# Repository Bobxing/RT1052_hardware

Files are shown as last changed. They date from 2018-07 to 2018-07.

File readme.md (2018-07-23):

# RT1052_hardware #

RT1052_hardware包含了野火RT1052系列开发板硬件相关的说明，包含如下内容：
* 原理图
* 机械尺寸图
* RT1052引脚分配表
* 核心板连接器的封装
* 板载元器件的封装

开发者可直接使用以上提供的器件封装，或参考原理图对自己的应用进行定制。

开发板配套的资料如下：
* [野火RT1052开发板配套程序](https://github.com/WildFire-Git/RT1052_code)

* [野火i.MX RT库开发实战指南](https://github.com/WildFire-Git/RT1052_doc)

开发者可直接使用我们的程序进行学习或对应用进行定制。

## 许可证 ##
MIT

## 联系我们 ##
* 电子邮箱:embedfire@embedfire.com
* 野火官网:http://www.embedfire.com
* 野火论坛:http://www.firebbs.cn
* 淘宝店铺:http://fire-stm32.taobao.com

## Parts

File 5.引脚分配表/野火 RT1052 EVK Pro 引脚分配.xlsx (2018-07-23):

 |  |  |  | 开发板分配的第一功能 | 开发板分配的第二功能
核心板引脚编号 | 底板排针引脚编号 | 核心板网络标号 | 芯片引脚定义 | ALT0（复用功能0） | ALT1（复用功能1） | ALT2（复用功能2） | ALT3（复用功能3） | ALT4（复用功能4） | ALT5（复用功能5） | ALT6（复用功能6） | ALT7（复用功能7） | ADC #1 | ADC #2 | ACMP #1 | ACMP #2 | ACMP #3 | ACMP #4
CN2-43 | B-43 | USB_OTG2_ID | GPIO_AD_B0_00 | FLEXPWM2_PWMA03 | XBAR1_INOUT14 | REF_CLK_32K | USB_OTG2_ID | LPI2C1_SCLS | GPIO1_IO00 | USDHC1_RESET_B | LPSPI3_SCK |  |  | ACMP1_IN4
CN2-41 | B-41 | USB_OTG1_ID | GPIO_AD_B0_01 | FLEXPWM2_PWMB03 | XBAR1_INOUT15 | REF_CLK_24M | USB_OTG1_ID | LPI2C1_SDAS | GPIO1_IO01 | EWM_OUT_B | LPSPI3_SDO |  |  |  | ACMP2_IN4
CN2-14 | B-14 | CTP_RST | GPIO_AD_B0_02 | FLEXCAN2_TX | XBAR1_INOUT16 | LPUART6_TX | USB_OTG1_PWR | FLEXPWM1_PWMX00 | GPIO1_IO02 | LPI2C1_HREQ | LPSPI3_SDI |  |  |  |  | ACMP3_IN4
CN2-16 | B-16 | USB OTG OC | GPIO_AD_B0_03 | FLEXCAN2_RX | XBAR1_INOUT17 | LPUART6_RX | USB_OTG1_OC | FLEXPWM1_PWMX01 | GPIO1_IO03 | REF_CLK_24M | LPSPI3_PCS0 |  |  |  |  |  | ACMP4_IN4
CN2-18 | B-18 | LCD_PWR_EN | GPIO_AD_B0_04 | SRC_BOOT_MODE00 | MQS_RIGHT | ENET_TX_DATA03 | SAI2_TX_SYNC | CSI_DATA09 | GPIO1_IO04 | PIT_TRIGGER00 | LPSPI3_PCS1
CN2-20 | B-20 | SD_PWR_EN | GPIO_AD_B0_05 | SRC_BOOT_MODE01 | MQS_LEFT | ENET_TX_DATA02 | SAI2_TX_BCLK | CSI_DATA08 | GPIO1_IO05 | XBAR1_INOUT17 | LPSPI3_PCS2
CN2-3 | B-3 | JTAG_TMS | GPIO_AD_B0_06 | JTAG_TMS | GPT2_COMPARE1 | ENET_RX_CLK | SAI2_RX_BCLK | CSI_DATA07 | GPIO1_IO06 | XBAR1_INOUT18 | LPSPI3_PCS3
CN2-2 | B-2 | JTAG_TCK | GPIO_AD_B0_07 | JTAG_TCK | GPT2_COMPARE2 | ENET_TX_ER | SAI2_RX_SYNC | CSI_DATA06 | GPIO1_IO07 | XBAR1_INOUT19 | ENET_1588_EVENT3_OUT
 |  |  | GPIO_AD_B0_08 | JTAG_MOD | GPT2_COMPARE3 | ENET_RX_DATA03 | SAI2_RX_DATA | CSI_DATA05 | GPIO1_IO08 | XBAR1_IN20 | ENET_1588_EVENT3_IN
CN2-1 | B-1 | JTAG_TDI | GPIO_AD_B0_09 | JTAG_TDI | FLEXPWM2_PWMA03 | ENET_RX_DATA02 | SAI2_TX_DATA | CSI_DATA04 | GPIO1_IO09 | XBAR1_IN21 | GPT2_CLK
CN2-4 | B-4 | JTAG_TDO | GPIO_AD_B0_10 | JTAG_TDO | FLEXPWM1_PWMA03 | ENET_CRS | SAI2_MCLK | CSI_DATA03 | GPIO1_IO10 | XBAR1_IN22 | ENET_1588_EVENT0_OUT
CN2-5 | B-5 | CTP_IRQ | GPIO_AD_B0_11 | JTAG_TRSTB | FLEXPWM1_PWMB03 | ENET_COL | WDOG1_WDOG_B | CSI_DATA02 | GPIO1_IO11 | XBAR1_IN23 | ENET_1588_EVENT0_IN
CN2-9 | B-9 | UART1_TX | GPIO_AD_B0_12 | LPI2C4_SCL | CCM_PMIC_READY | LPUART1_TX | WDOG2_WDOG_B | FLEXPWM1_PWMX02 | GPIO1_IO12 | ENET_1588_EVENT1_OUT |  | ADC1_IN1
CN2-11 | B-11 | UART1_RX | GPIO_AD_B0_13 | LPI2C4_SDA | GPT1_CLK | LPUART1_RX | EWM_OUT_B | FLEXPWM1_PWMX03 | GPIO1_IO13 | ENET_1588_EVENT1_IN | REF_CLK_24M | ADC1_IN2 |  | ACMP1_IN2
CN2-17 | B-17 | CAN2_TX | GPIO_AD_B0_14 | USB_OTG2_OC | XBAR1_IN24 | LPUART1_CTS_B | ENET_1588_EVENT0_OUT | CSI_VSYNC | GPIO1_IO14 | FLEXCAN2_TX |  | ADC1_IN3 |  |  | ACMP2_IN2
CN2-19 | B-19 | CAN2_RX | GPIO_AD_B0_15 | USB_OTG2_PWR | XBAR1_IN25 | LPUART1_RTS_B | ENET_1588_EVENT0_IN | CSI_HSYNC | GPIO1_IO15 | FLEXCAN2_RX | WDOG1_WDOG_RST_B_DEB | ADC1_IN4 |  |  |  | ACMP3_IN2
CN2-21 | B-21 | I2C1_SCL | GPIO_AD_B1_00 | USB_OTG2_ID | QTIMER3_TIMER0 | LPUART2_CTS_B | LPI2C1_SCL | WDOG1_B | GPIO1_IO16 | USDHC1_WP | KPP_ROW07 | ADC1_IN5 | ADC2_IN5 |  |  |  | ACMP4_IN2
CN2-23 | B-23 | I2C1_SDA | GPIO_AD_B1_01 | USB_OTG1_PWR | QTIMER3_TIMER1 | LPUART2_RTS_B | LPI2C1_SDA | CCM_PMIC_READY | GPIO1_IO17 | USDHC1_VSELECT | KPP_COL07 | ADC1_IN6 | ADC2_IN6 | ACMP1_IN0 | ACMP2_IN0 | ACMP3_IN0 | ACMP4_IN0
CN2-10 | B-10 | SPDIF_OUT | GPIO_AD_B1_02 | USB_OTG1_ID | QTIMER3_TIMER2 | LPUART2_TX | SPDIF_OUT | ENET_1588_EVENT2_OUT | GPIO1_IO18 | USDHC1_CD_B | KPP_ROW06 | ADC1_IN7 | ADC2_IN7 | ACMP1_IN3
CN2-8 | B-23 | SPDIF_IN | GPIO_AD_B1_03 | USB_OTG1_OC | QTIMER3_TIMER3 | LPUART2_RX | SPDIF_IN | ENET_1588_EVENT2_IN | GPIO1_IO19 | USDHC2_CD_B | KPP_COL06 | ADC1_IN8 | ADC2_IN8 |  | ACMP2_IN3
CN1-16 | A-16 | GPIO_AD_B1_04 | GPIO_AD_B1_04 | FLEXSPIB_DATA03 | ENET_MDC | LPUART3_CTS_B | SPDIF_SR_CLK | CSI_PIXCLK | GPIO1_IO20 | USDHC2_DATA0 | KPP_ROW05 | ADC1_IN9 | ADC2_IN9 |  |  | ACMP3_IN3
CN2-24 | B-24 | GPIO_AD_B1_05 | GPIO_AD_B1_05 | FLEXSPIB_DATA02 | ENET_MDIO | LPUART3_RTS_B | SPDIF_OUT | CSI_MCLK | GPIO1_IO21 | USDHC2_DATA1 | KPP_COL05 | ADC1_IN10 | ADC2_IN10 |  |  |  | ACMP4_IN3
CN2-26 | B-26 | GPIO_AD_B1_06 | GPIO_AD_B1_06 | FLEXSPIB_DATA01 | LPI2C3_SDA | LPUART3_TX | SPDIF_LOCK | CSI_VSYNC | GPIO1_IO22 | USDHC2_DATA2 | KPP_ROW04 | ADC1_IN11 | ADC2_IN11 | ACMP1_IN1 | ACMP2_IN1 | ACMP3_IN1 | ACMP4_IN1
CN2-28 | B-28 | GPIO_AD_B1_07 | GPIO_AD_B1_07 | FLEXSPIB_DATA00 | LPI2C3_SCL | LPUART3_RX | SPDIF_EXT_CLK | CSI_HSYNC | GPIO1_IO23 | USDHC2_DATA3 | KPP_COL04 | ADC1_IN12 | ADC2_IN12 | ACMP1_IN5
CN2-30 | B-30 | GPIO_AD_B1_08 | GPIO_AD_B1_08 | FLEXSPIA_SS1_B | FLEXPWM4_PWMA00 | FLEXCAN1_TX | CCM_PMIC_READY | CSI_DATA09 | GPIO1_IO24 | USDHC2_CMD | KPP_ROW03 | ADC1_IN13 | ADC2_IN13 |  | ACMP2_IN5
CN2-35 | B-35 | SAI1_MCLK | GPIO_AD_B1_09 | FLEXSPIA_DQS | FLEXPWM4_PWMA01 | FLEXCAN1_RX | SAI1_MCLK | CSI_DATA08 | GPIO1_IO25 | USDHC2_CLK | KPP_COL03 | ADC1_IN14 | ADC2_IN14 |  |  | ACMP3_IN5
CN2-31 | B-31 | SAI1_RX_SYNC | GPIO_AD_B1_10 | FLEXSPIA_DATA03 | WDOG1_B | LPUART8_TX | SAI1_RX_SYNC | CSI_DATA07 | GPIO1_IO26 | USDHC2_WP | KPP_ROW02 | ADC1_IN15 | ADC2_IN15 |  |  |  | ACMP4_IN5
CN2-29 | B-29 | SAI1_RX_BCLK | GPIO_AD_B1_11 | FLEXSPIA_DATA02 | EWM_OUT_B | LPUART8_RX | SAI1_RX_BCLK | CSI_DATA06 | GPIO1_IO27 | USDHC2_RESET_B | KPP_COL02 | ADC1_IN0 | ADC2_IN0 | ACMP1_IN6
CN2-33 | B-33 | SAI1_RXD | GPIO_AD_B1_12 | FLEXSPIA_DATA01 | ACMP_OUT00 | LPSPI3_PCS0 | SAI1_RX_DATA00 | CSI_DATA05 | GPIO1_IO28 | USDHC2_DATA4 | KPP_ROW01 |  | ADC2_IN1 | ACMP1_OUT | ACMP2_IN6
CN2-36 | B-36 | SAI1_TXD | GPIO_AD_B1_13 | FLEXSPIA_DATA00 | ACMP_OUT01 | LPSPI3_SDI | SAI1_TX_DATA00 | CSI_DATA04 | GPIO1_IO29 | USDHC2_DATA5 | KPP_COL01 |  | ADC2_IN2 |  | ACMP2_OUT | ACMP3_IN6
CN2-34 | B-34 | SAI1_TX_BCLK | GPIO_AD_B1_14 | FLEXSPIA_SCLK | ACMP_OUT02 | LPSPI3_SDO | SAI1_TX_BCLK | CSI_DATA03 | GPIO1_IO30 | USDHC2_DATA6 | KPP_ROW00 |  | ADC2_IN3 |  |  | ACMP3_OUT | ACMP4_IN6
CN2-32 | B-32 | SAI1_TX_SYNC | GPIO_AD_B1_15 | FLEXSPIA_SS0_B | ACMP_OUT03 | LPSPI3_SCK | SAI1_TX_SYNC | CSI_DATA02 | GPIO1_IO31 | USDHC2_DATA7 | KPP_COL00 |  | ADC2_IN4 |  |  |  | ACMP4_OUT
CN1-37 | A-37 | LCDIF_CLK | GPIO_B0_00 | LCD_CLK | QTIMER1_TIMER0 | MQS_RIGHT | LPSPI4_PCS0 | FLEXIO2_FLEXIO00 | GPIO2_IO00 | SEMC_CSX01
CN1-38 | A-38 | LCDIF_ENA | GPIO_B0_01 | LCD_ENABLE | QTIMER1_TIMER1 | MQS_LEFT | LPSPI4_SDI | FLEXIO2_FLEXIO01 | GPIO2_IO01 | SEMC_CSX02
CN1-36 | A-36 | LCDIF_HSYNC | GPIO_B0_02 | LCD_HSYNC | QTIMER1_TIMER2 | FLEXCAN1_TX | LPSPI4_SDO | FLEXIO2_FLEXIO02 | GPIO2_IO02 | SEMC_CSX03
CN1-35 | A-35 | LCDIF_VSYNC | GPIO_B0_03 | LCD_VSYNC | QTIMER2_TIMER0 | FLEXCAN1_RX | LPSPI4_SCK | FLEXIO2_FLEXIO03 | GPIO2_IO03 | WDOG2_RESET_B_DEB
CN1-19 | A-19 | LCDIF_D0 (B3) | GPIO_B0_04 | LCD_DATA00 (B3) | QTIMER2_TIMER1 | LPI2C2_SCL |  | FLEXIO2_FLEXIO04 | GPIO2_IO04 | SRC_BOOT_CFG00
CN1-20 | A-20 | LCDIF_D1 (B4) | GPIO_B0_05 | LCD_DATA01 (B4) | QTIMER2_TIMER2 | LPI2C2_SDA |  | FLEXIO2_FLEXIO05 | GPIO2_IO05 | SRC_BOOT_CFG01
CN1-21 | A-21 | LCDIF_D2 (B5) | GPIO_B0_06 | LCD_DATA02 (B5) | QTIMER3_TIMER0 | FLEXPWM2_PWMA00 |  | FLEXIO2_FLEXIO06 | GPIO2_IO06 | SRC_BOOT_CFG02
CN1-22 | A-22 | LCDIF_D3 (B6) | GPIO_B0_07 | LCD_DATA03 (B6) | QTIMER3_TIMER1 | FLEXPWM2_PWMB00 |  | FLEXIO2_FLEXIO07 | GPIO2_IO07 | SRC_BOOT_CFG03
CN1-23 | A-23 | LCDIF_D4 (B7) | GPIO_B0_08 | LCD_DATA04 (B7) | QTIMER3_TIMER2 | FLEXPWM2_PWMA01 | LPUART3_TX | FLEXIO2_FLEXIO08 | GPIO2_IO08 | SRC_BOOT_CFG04
CN1-24 | A-24 | LCDIF_D5 (G2) | GPIO_B0_09 | LCD_DATA05 (G2) | QTIMER4_TIMER0 | FLEXPWM2_PWMB01 | LPUART3_RX | FLEXIO2_FLEXIO09 | GPIO2_IO09 | SRC_BOOT_CFG05
CN1-25 | A-25 | LCDIF_D6 (G3) | GPIO_B0_10 | LCD_DATA06 (G3) | QTIMER4_TIMER1 | FLEXPWM2_PWMA02 | SAI1_TX_DATA03 | FLEXIO2_FLEXIO10 | GPIO2_IO10 | SRC_BOOT_CFG06
CN1-26 | A-26 | LCDIF_D7 (G4) | GPIO_B0_11 | LCD_DATA07 (G4) | QTIMER4_TIMER2 | FLEXPWM2_PWMB02 | SAI1_TX_DATA02 | FLEXIO2_FLEXIO11 | GPIO2_IO11 | SRC_BOOT_CFG07
CN1-27 | A-27 | LCDIF_D8 (G5) | GPIO_B0_12 | LCD_DATA08 (G5) | XBAR1_INOUT10 |  | SAI1_TX_DATA01 | FLEXIO2_FLEXIO12 | GPIO2_IO12 | SRC_BOOT_CFG08
CN1-28 | A-28 | LCDIF_D9 (G6) | GPIO_B0_13 | LCD_DATA09 (G6) | XBAR1_INOUT11 |  | SAI1_MCLK | FLEXIO2_FLEXIO13 | GPIO2_IO13 | SRC_BOOT_CFG09
CN1-29 | A-29 | LCDIF_D10 (G7) | GPIO_B0_14 | LCD_DATA10 (G7) | XBAR1_INOUT12 | ARM_CM7_TXEV | SAI1_RX_SYNC | FLEXIO2_FLEXIO14 | GPIO2_IO14 | SRC_BOOT_CFG10
CN1-30 | A-30 | LCDIF_D11 (R3) | GPIO_B0_15 | LCD_DATA11 (R3) | XBAR1_INOUT13 | ARM_CM7_RXEV | SAI1_RX_BCLK | FLEXIO2_FLEXIO15 | GPIO2_IO15 | SRC_BOOT_CFG11
CN1-31 | A-31 | LCDIF_D12 (R4) | GPIO_B1_00 | LCD_DATA12 (R4) | XBAR1_INOUT14 | LPUART4_TX | SAI1_RX_DATA00 | FLEXIO2_FLEXIO16 | GPIO2_IO16 | FLEXPWM1_PWMA03
CN1-32 | A-32 | LCDIF_D13 (R5) | GPIO_B1_01 | LCD_DATA13 (R5) | XBAR1_INOUT15 | LPUART4_RX | SAI1_TX_DATA00 | FLEXIO2_FLEXIO17 | GPIO2_IO17 | FLEXPWM1_PWMB03
CN1-33 | A-33 | LCDIF_D14 (R6) | GPIO_B1_02 | LCD_DATA14 (R6) | XBAR1_INOUT16 | LPSPI4_PCS2 | SAI1_TX_BCLK | FLEXIO2_FLEXIO18 | GPIO2_IO18 | FLEXPWM2_PWMA03
CN1-34 | A-34 | LCDIF_D15 (R7) | GPIO_B1_03 | LCD_DATA15 (R7) | XBAR1_INOUT17 | LPSPI4_PCS1 | SAI1_TX_SYNC | FLEXIO2_FLEXIO19 | GPIO2_IO19 | FLEXPWM2_PWMB03
CN1-10 | A-10 | ENET_RXD0 | GPIO_B1_04 | LCD_DATA16 | LPSPI4_PCS0 | CSI_DATA15 | ENET_RX_DATA00 | FLEXIO2_FLEXIO20 | GPIO2_IO20
CN1-12 | A-12 | ENET_RXD1 | GPIO_B1_05 | LCD_DATA17 | LPSPI4_SDI | CSI_DATA14 | ENET_RX_DATA01 | FLEXIO2_FLEXIO21 | GPIO2_IO21
CN1-15 | A-15 | ENET_CRS_DV | GPIO_B1_06 | LCD_DATA18 | LPSPI4_SDO | CSI_DATA13 | ENET_RX_EN | FLEXIO2_FLEXIO22 | GPIO2_IO22
CN1-11 | A-11 | ENET_TXD0 | GPIO_B1_07 | LCD_DATA19 | LPSPI4_SCK | CSI_DATA12 | ENET_TX_DATA00 | FLEXIO2_FLEXIO23 | GPIO2_IO23
CN1-13 | A-13 | ENET_TXD1 | GPIO_B1_08 | LCD_DATA20 | QTIMER1_TIMER3 | CSI_DATA11 | ENET_TX_DATA01 | FLEXIO2_FLEXIO24 | GPIO2_IO24 | FLEXCAN2_TX
CN1-9 | A-9 | ENET_TXEN | GPIO_B1_09 | LCD_DATA21 | QTIMER2_TIMER3 | CSI_DATA10 | ENET_TX_EN | FLEXIO2_FLEXIO25 | GPIO2_IO25 | FLEXCAN2_RX
CN1-17 | A-17 | ENET_TXCLK | GPIO_B1_10 | LCD_DATA22 | QTIMER3_TIMER3 | CSI_DATA00 | ENET_TX_CLK | FLEXIO2_FLEXIO26 | GPIO2_IO26 | ENET_REF_CLK
CN1-14 | A-14 | ENET_RXER | GPIO_B1_11 | LCD_DATA23 | QTIMER4_TIMER3 | CSI_DATA01 | ENET_RX_ER | FLEXIO2_FLEXIO27 | GPIO2_IO27 | LPSPI4_PCS3
CN2-13 | B-13 | UART5_TX | GPIO_B1_12 |  | LPUART5_TX | CSI_PIXCLK | ENET_1588_EVENT0_IN | FLEXIO2_FLEXIO28 | GPIO2_IO28 | USDHC1_CD_B
CN2-15 | B-15 | UART5_RX | GPIO_B1_13 | WDOG1_B | LPUART5_RX | CSI_VSYNC | ENET_1588_EVENT0_OUT | FLEXIO2_FLEXIO29 | GPIO2_IO29 | USDHC1_WP
CN2-63 | B-63 | SD0_VSELECT | GPIO_B1_14 | ENET_MDC | FLEXPWM4_PWMA02 | CSI_HSYNC | XBAR1_IN02 | FLEXIO2_FLEXIO30 | GPIO2_IO30 | USDHC1_VSELECT
CN1-18 | A-18 | ENET_MDIO | GPIO_B1_15 | ENET_MDIO | FLEXPWM4_PWMA03 | CSI_MCLK | XBAR1_IN03 | FLEXIO2_FLEXIO31 | GPIO2_IO31 | USDHC1_RESET_B
CN2-68 | B-68 | SD_CMD | GPIO_SD_B0_00 | USDHC1_CMD | FLEXPWM1_PWMA00 | LPI2C3_SCL | XBAR1_INOUT04 | LPSPI1_SCK | GPIO3_IO12 | FLEXSPIA_SS1_B
CN2-70 | B-70 | SD_CLK | GPIO_SD_B0_01 | USDHC1_CLK | FLEXPWM1_PWMB00 | LPI2C3_SDA | XBAR1_INOUT05 | LPSPI1_PCS0 | GPIO3_IO13 | FLEXSPIB_SS1_B
CN2-65 | B-65 | SD_D0 | GPIO_SD_B0_02 | USDHC1_DATA0 | FLEXPWM1_PWMA01 | LPUART8_CTS_B | XBAR1_INOUT06 | LPSPI1_SDO | GPIO3_IO14
CN2-67 | B-67 | SD_D1 | GPIO_SD_B0_03 | USDHC1_DATA1 | FLEXPWM1_PWMB01 | LPUART8_RTS_B | XBAR1_INOUT07 | LPSPI1_SDI | GPIO3_IO15
CN2-69 | B-69 | SD_D2 | GPIO_SD_B0_04 | USDHC1_DATA2 | FLEXPWM1_PWMA02 | LPUART8_TX | XBAR1_INOUT08 | FLEXSPIB_SS0_B | GPIO3_IO16 | CCM_CLKO1
CN2-66 | B-66 | SD_D3 | GPIO_SD_B0_05 | USDHC1_DATA3 | FLEXPWM1_PWMB02 | LPUART8_RX | XBAR1_INOUT09 | FLEXSPIB_DQS | GPIO3_IO17 | CCM_CLKO2
CN2-62 | B-62 | FlexSPI_D3_B | GPIO_SD_B1_00 | USDHC2_DATA3 | FLEXSPIB_DATA03 | FLEXPWM1_PWMA03 | SAI1_TX_DATA03 | LPUART4_TX | GPIO3_IO00
CN2-60 | B-60 | FlexSPI_D2_B | GPIO_SD_B1_01 | USDHC2_DATA2 | FLEXSPIB_DATA02 | FLEXPWM1_PWMB03 | SAI1_TX_DATA02 | LPUART4_RX | GPIO3_IO01
CN2-58 | B-58 | FlexSPI_D1_B | GPIO_SD_B1_02 | USDHC2_DATA1 | FLEXSPIB_DATA01 | FLEXPWM2_PWMA03 | SAI1_TX_DATA01 | FLEXCAN1_TX | GPIO3_IO02 | CCM_WAIT
CN2-56 | B-56 | FlexSPI_D0_B | GPIO_SD_B1_03 | USDHC2_DATA0 | FLEXSPIB_DATA00 | FLEXPWM2_PWMB03 | SAI1_MCLK | FLEXCAN1_RX | GPIO3_IO03 | CCM_PMIC_READY
CN2-54 | B-54 | FlexSPI_CLK_B | GPIO_SD_B1_04 | USDHC2_CLK | FLEXSPIB_SCLK | LPI2C1_SCL | SAI1_RX_SYNC | FLEXSPIA_SS1_B | GPIO3_IO04 | CCM_STOP
CN2-52 | B-52 | FlexSPI_DQS | GPIO_SD_B1_05 | USDHC2_CMD | FLEXSPIA_DQS | LPI2C1_SDA | SAI1_RX_BCLK | FLEXSPIB_SS0_B | GPIO3_IO05
CN2-51 | B-51 | FlexSPI_SS0 | GPIO_SD_B1_06 | USDHC2_RESET_B | FLEXSPIA_SS0_B | LPUART7_CTS_B | SAI1_RX_DATA00 | LPSPI2_PCS0 | GPIO3_IO06
CN2-53 | B-53 | FlexSPI_CLK | GPIO_SD_B1_07 | SEMC_CSX01 | FLEXSPIA_SCLK | LPUART7_RTS_B | SAI1_TX_DATA00 | LPSPI2_SCK | GPIO3_IO07 | CCM_REF_EN_B
CN2-55 | B-55 | FlexSPI_D0_A | GPIO_SD_B1_08 | USDHC2_DATA4 | FLEXSPIA_DATA00 | LPUART7_TX | SAI1_TX_BCLK | LPSPI2_SD0 | GPIO3_IO08 | SEMC_CSX02
CN2-57 | B-57 | FlexSPI_D1_A | GPIO_SD_B1_09 | USDHC2_DATA5 | FLEXSPIA_DATA01 | LPUART7_RX | SAI1_TX_SYNC | LPSPI2_SDI | GPIO3_IO09
CN2-59 | B-59 | FlexSPI_D2_A | GPIO_SD_B1_10 | USDHC2_DATA6 | FLEXSPIA_DATA02 | LPUART2_RX | LPI2C2_SDA | LPSPI2_PCS2 | GPIO3_IO10
CN2-61 | B-61 | FlexSPI_D3_A | GPIO_SD_B1_11 | USDHC2_DATA7 | FLEXSPIA_DATA03 | LPUART2_TX | LPI2C2_SCL | LPSPI2_PCS3 | GPIO3_IO11
CN2-25 | B-25 | GPIO_EMC_40 | GPIO_EMC_40 | SEMC_RDY | GPT2_CAPTURE2 | LPSPI1_PCS2 | USB_OTG2_OC | ENET_MDC | GPIO3_IO26 | USDHC2_RESET_B
CN2-27 | B-27 | GPIO_EMC_41 | GPIO_EMC_41 | SEMC_CSX00 | GPT2_CAPTURE1 | LPSPI1_PCS3 | USB_OTG2_PWR | ENET_MDIO | GPIO3_IO27 | USDHC1_VSELECT
CN2-37 | B-37 | CLK1_OUT_N
CN2-39 | B-39 | CLK1_OUT_P
CN2-38 | B-37 | OTG1_DP
CN2-40 | B-39 | OTG1_DN
CN2-42 | B-37 | OTG2_DN
CN2-44 | B-39 | OTG2_DP
CN2-50 | B-50 | ONOFF |  | SRC_RESET_B
CN2-47 | B-47 | POR_B |  | SRC_POR_B
CN2-48 | B-48 | KEY |  |  |  |  |  |  | GPIO5_IO00
CN2-49 | B-49 | PMIC_ON |  | CCM_PMIC_ON_REQ |  |  |  |  | GPIO5_IO01
CN2-45 | B-45 | PMIC_STBY |  | CCM_PMIC_VSTBY_REQ |  |  |  |  | GPIO5_IO01

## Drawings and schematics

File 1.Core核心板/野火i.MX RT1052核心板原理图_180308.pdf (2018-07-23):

D

C

B

A | A

目录

# Page 1 目录

# 野火i.MX RT1052核心板

# Page 2

# Page 3

# Page 4

# Page 5

# Page 6

# Page 8

# Page 7

# 历史版本

# 主电源

## MCU电源

## SDRAM

## MCU_GPIO

## LCD/KEY/BOOT CFG

SD

Page 9 | NAND FLASH/QSPI FLASH/E2PROM
Page 10 Page 11 | USB/JTAG/UART
| ETHERNET
Page 12 | 引出IO

Title

Size | Document Number | Rev
Date: | Sheet | of
目录 | V1.0

野火i.MX RT1052核心板

东莞野火电子技术有限公司
https://fire-stm32.taobao.com

A4

Thursday, March 08, 2018 | 1 | 12

Title

目录 | V1.0

野火i.MX RT1052核心板

东莞野火电子技术有限公司
https://fire-stm32.taobao.com
Thursday, March 08, 2018 | 1 | 12

Title

目录 | V1.0

野火i.MX RT1052核心板

东莞野火电子技术有限公司
https://fire-stm32.taobao.com
Thursday, March 08, 2018 | 1 | 12

D

C

B

A | A

# 历史版本

# 版本号

V0.1 | 2017-12-04
日期 | 设计 | 描述
| cancore | 初始版本
V0.2 | 2017-12-26 | cancore | 1.增加I2C上拉电阻 | 2.删除调试口电源供电，避免上电时序出错
V0.3 | 2018-01-13 | cancore | 1.Q2封装更正 2.SEMC_RDY增加上拉 3.C72不焊
V1.0 | 2018-02-6 | cancore | 1.删除WDOG相关电路 2.RTC供电串联100Ω电阻 3.USB供电增加保护电路

Title

历史版本 | V1.0

野火i.MX RT1052核心板

东莞野火电子技术有限公司
https://fire-stm32.taobao.com
Thursday, March 08, 2018 | 2 | 12

Title

历史版本 | V1.0

野火i.MX RT1052核心板

东莞野火电子技术有限公司
https://fire-stm32.taobao.com
Thursday, March 08, 2018 | 2 | 12

Title

历史版本 | V1.0

野火i.MX RT1052核心板

东莞野火电子技术有限公司
https://fire-stm32.taobao.com
Thursday, March 08, 2018 | 2 | 12

D

# R36/R39 = 4.5

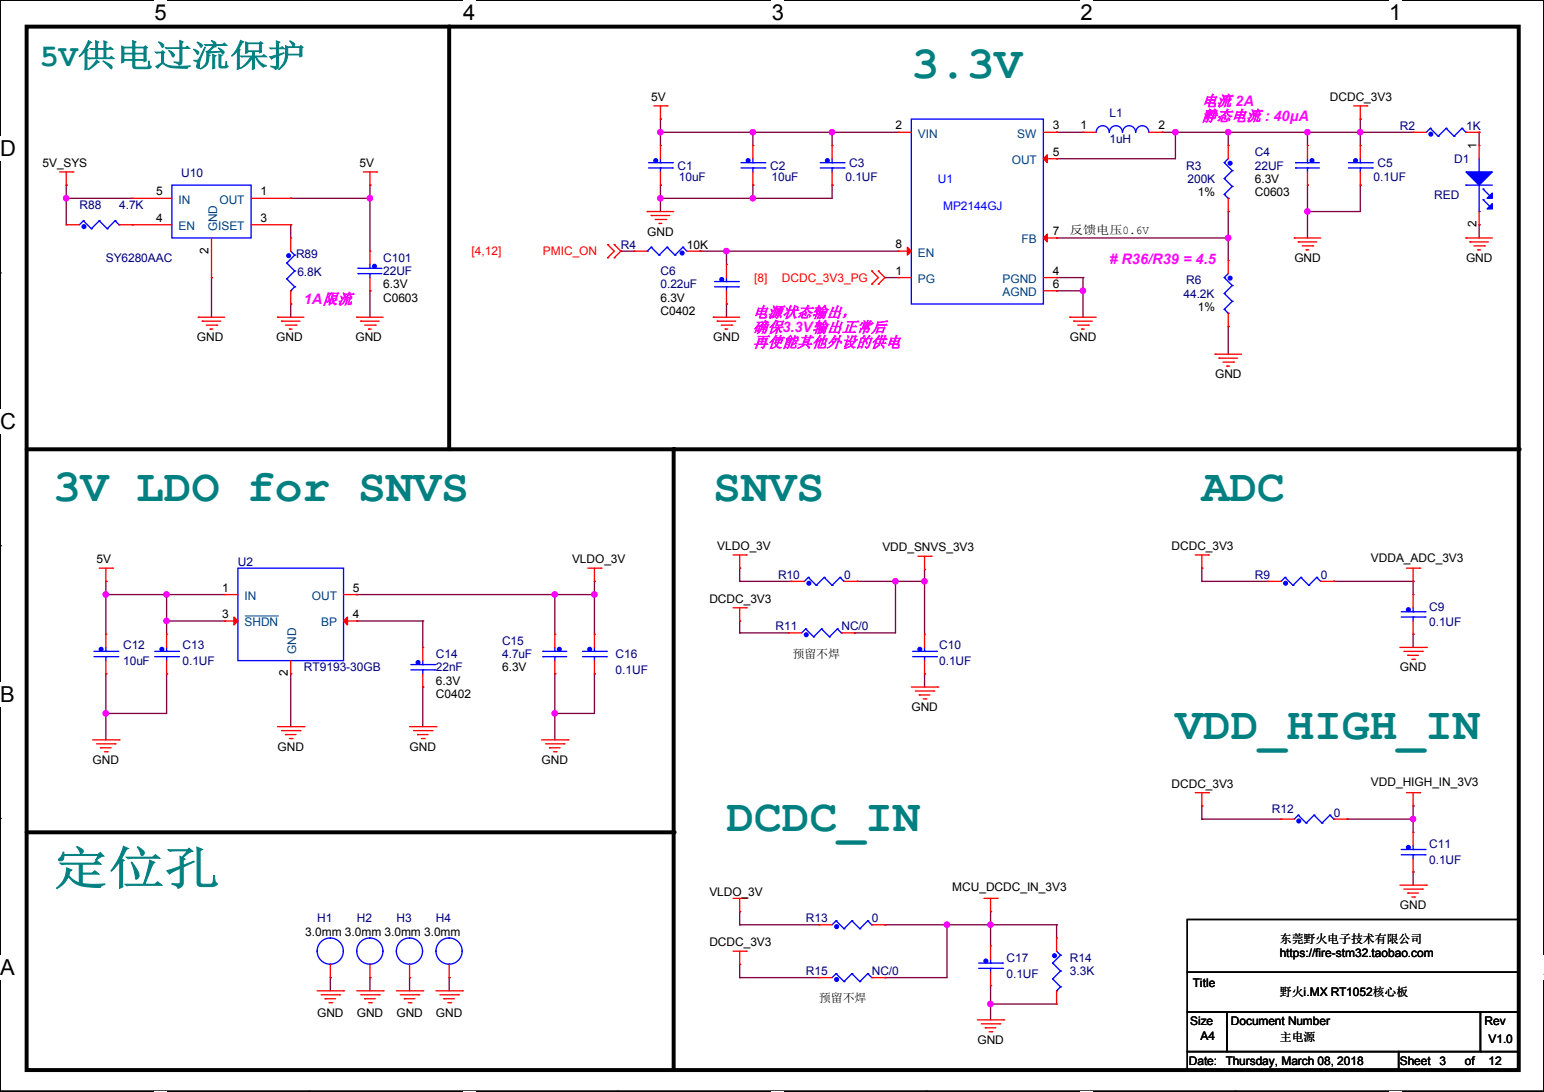
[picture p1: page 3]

东莞野火电子技术有限公司
https://fire-stm32.taobao.com

D

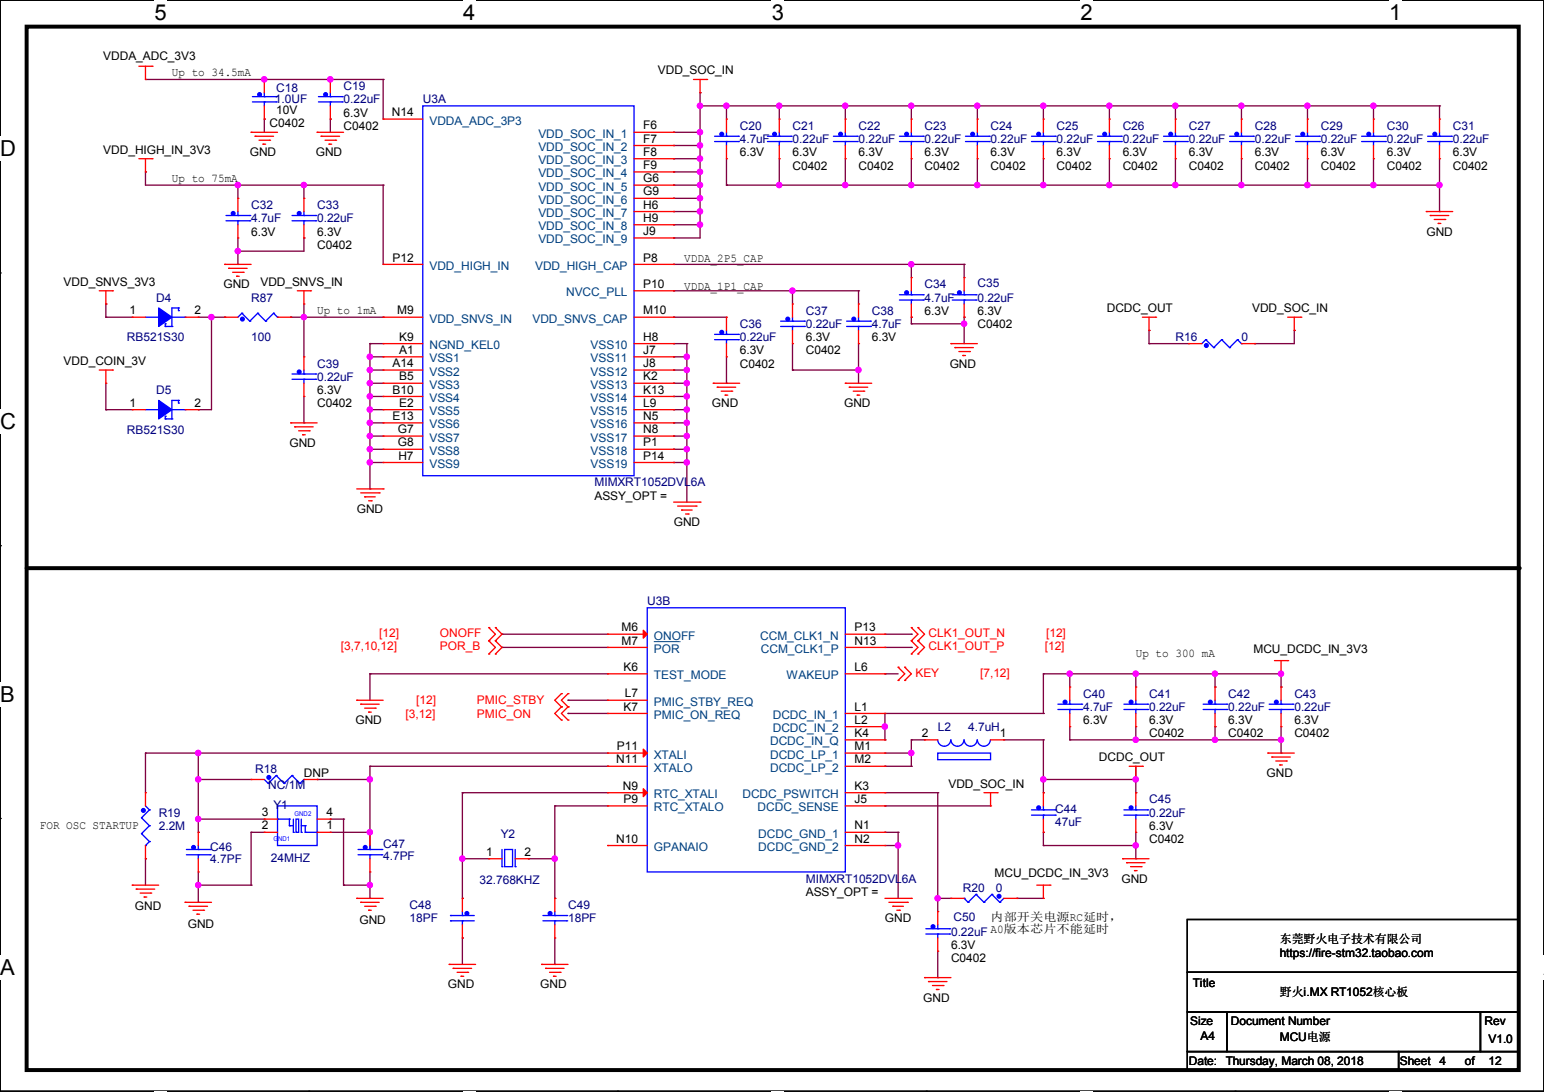
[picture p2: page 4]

东莞野火电子技术有限公司
https://fire-stm32.taobao.com

D

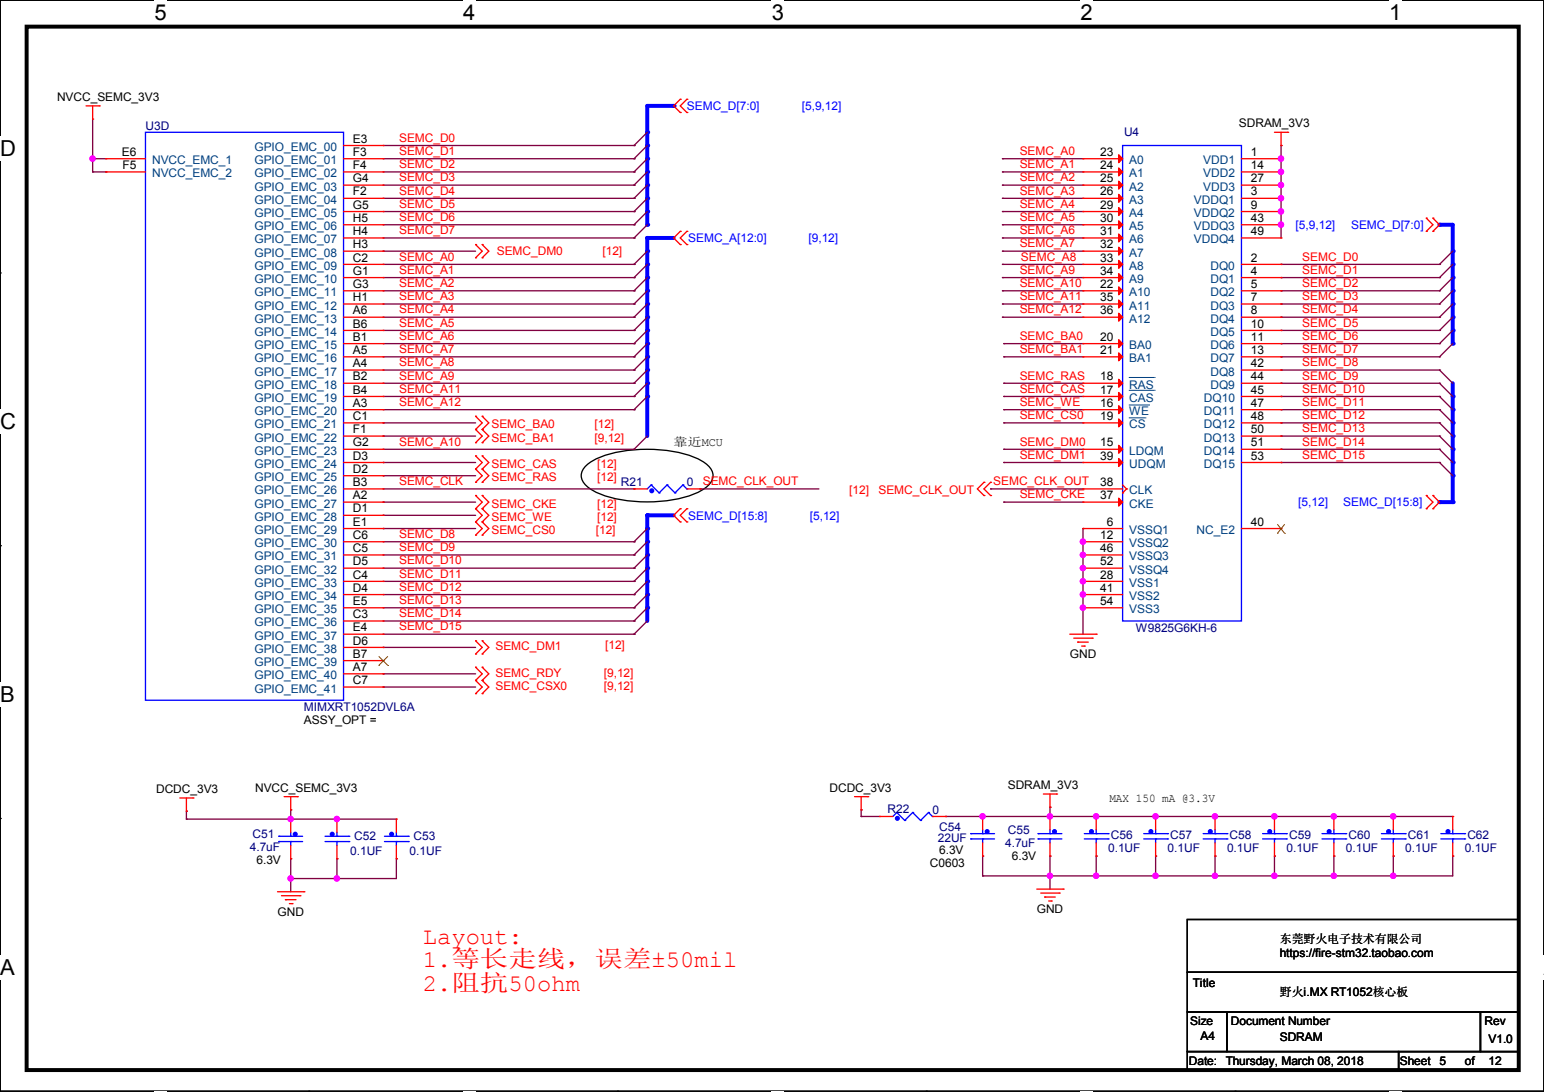
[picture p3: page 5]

东莞野火电子技术有限公司
https://fire-stm32.taobao.com

D

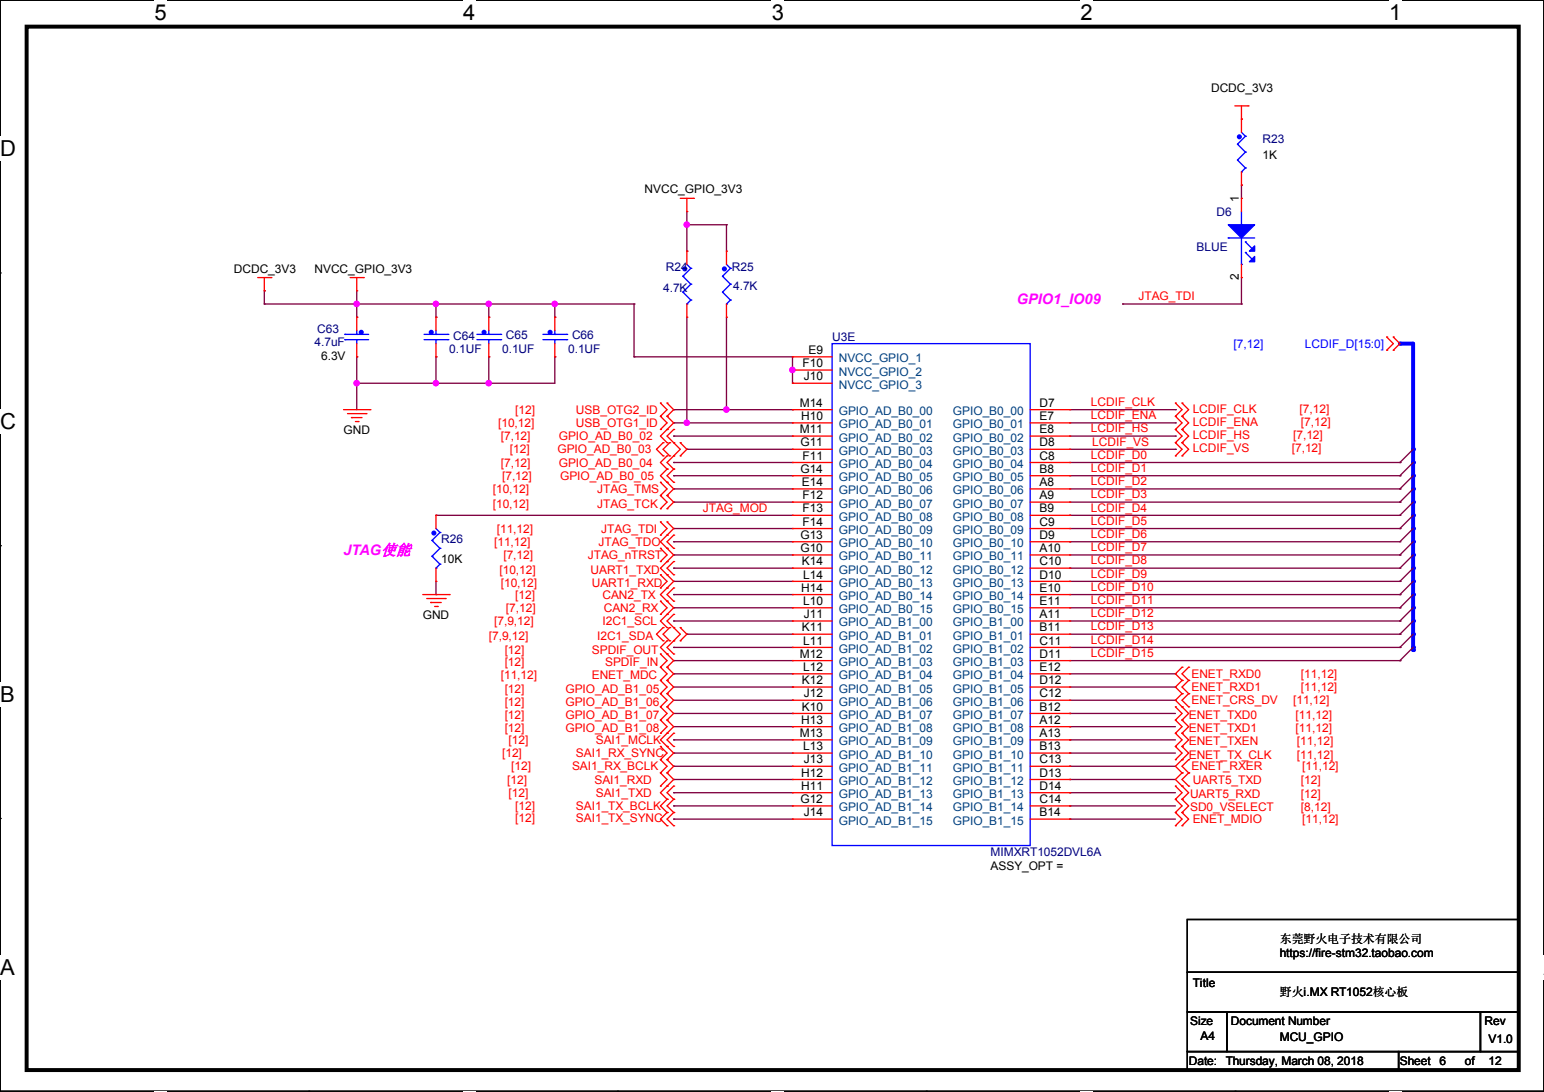
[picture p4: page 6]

东莞野火电子技术有限公司
https://fire-stm32.taobao.com

D

# BOOT_MODE1 BOOT_MODE0

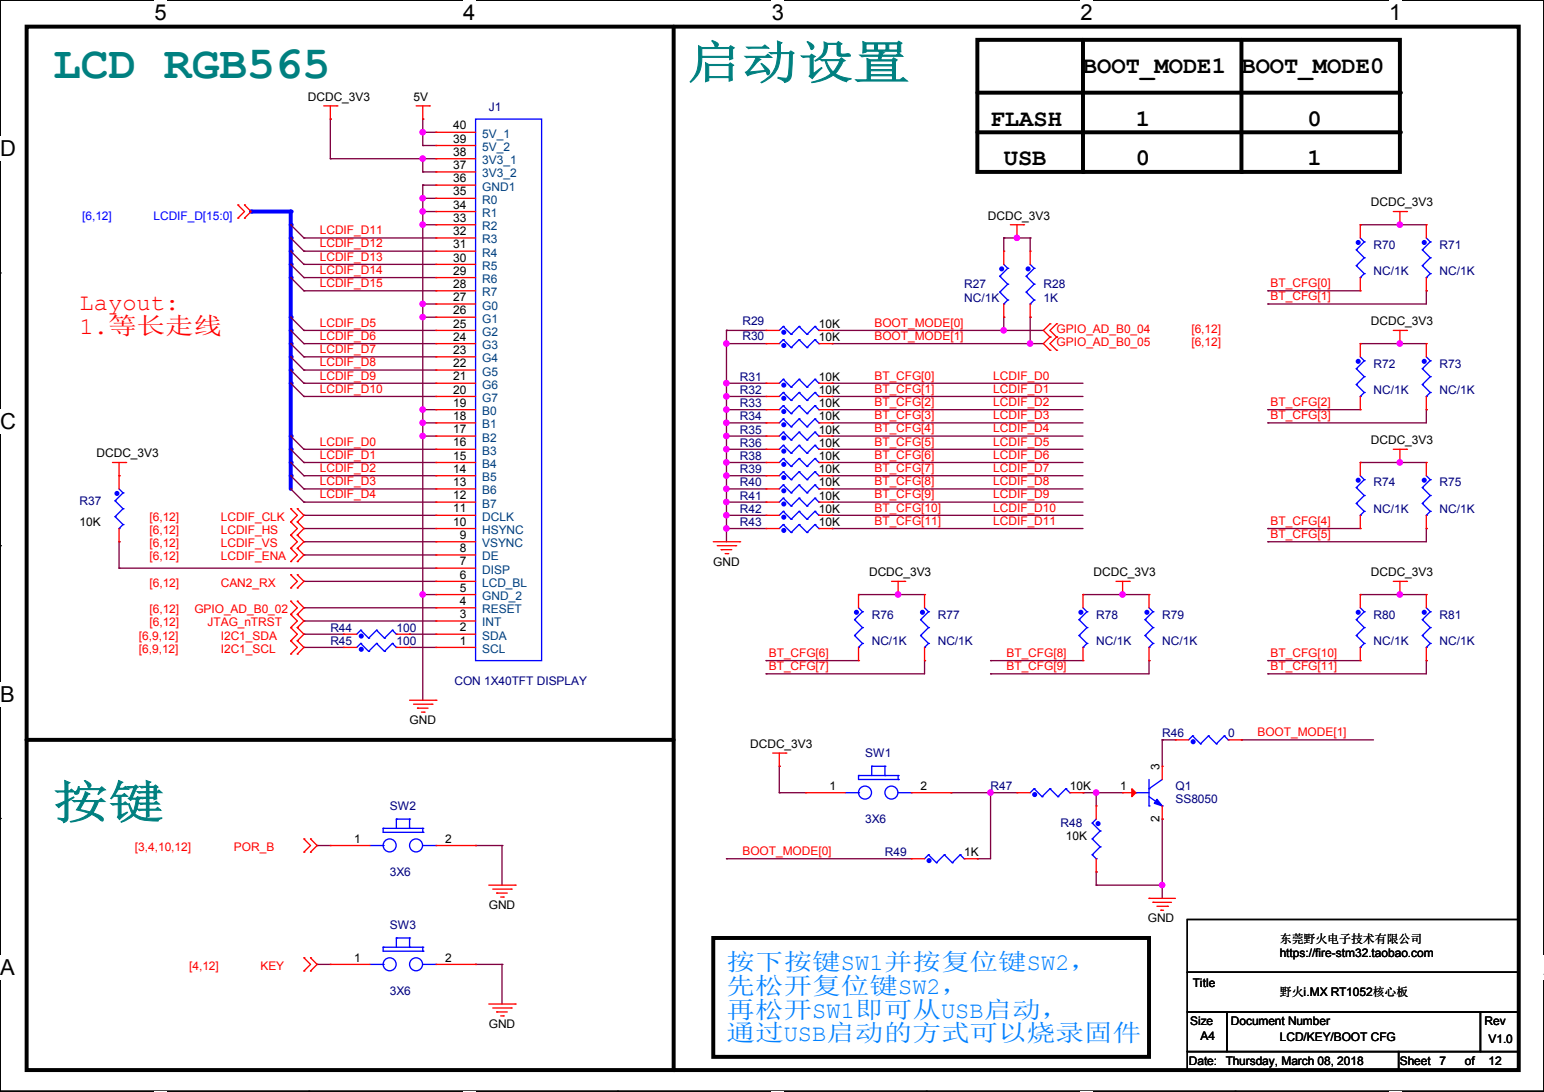
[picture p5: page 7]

东莞野火电子技术有限公司
https://fire-stm32.taobao.com

D

# Layout:

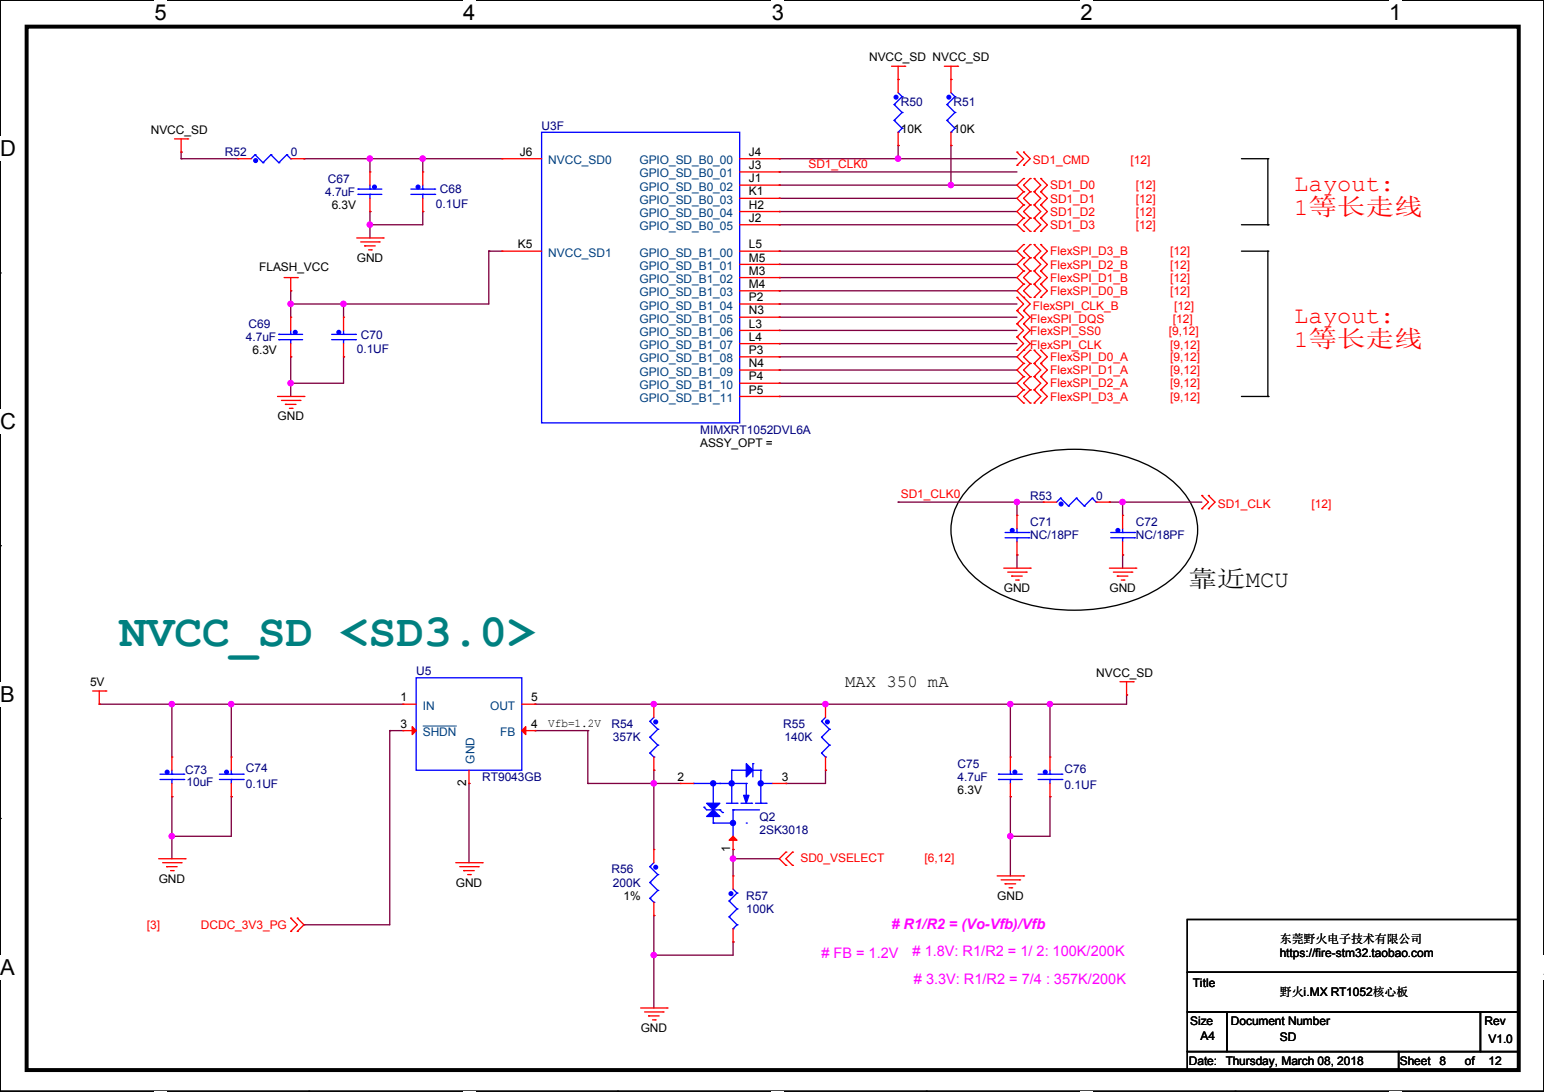
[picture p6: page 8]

东莞野火电子技术有限公司
https://fire-stm32.taobao.com

D

NAND FLASH | EEPROM

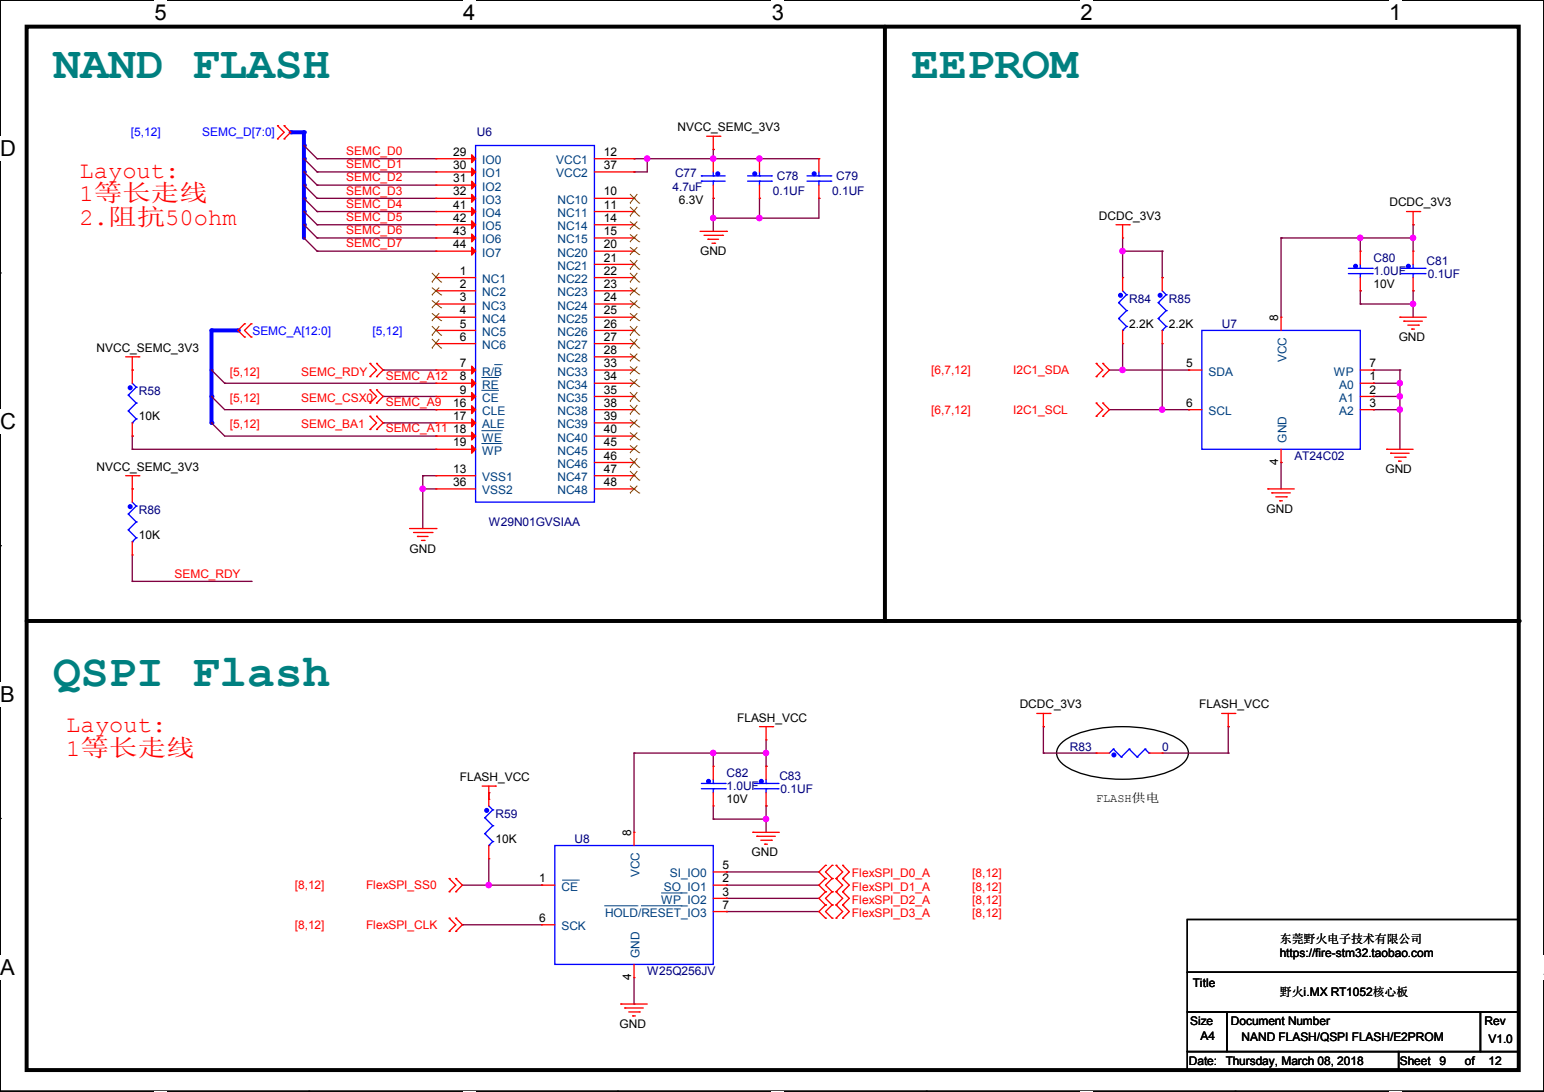
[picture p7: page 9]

东莞野火电子技术有限公司
https://fire-stm32.taobao.com

D

# 调试口

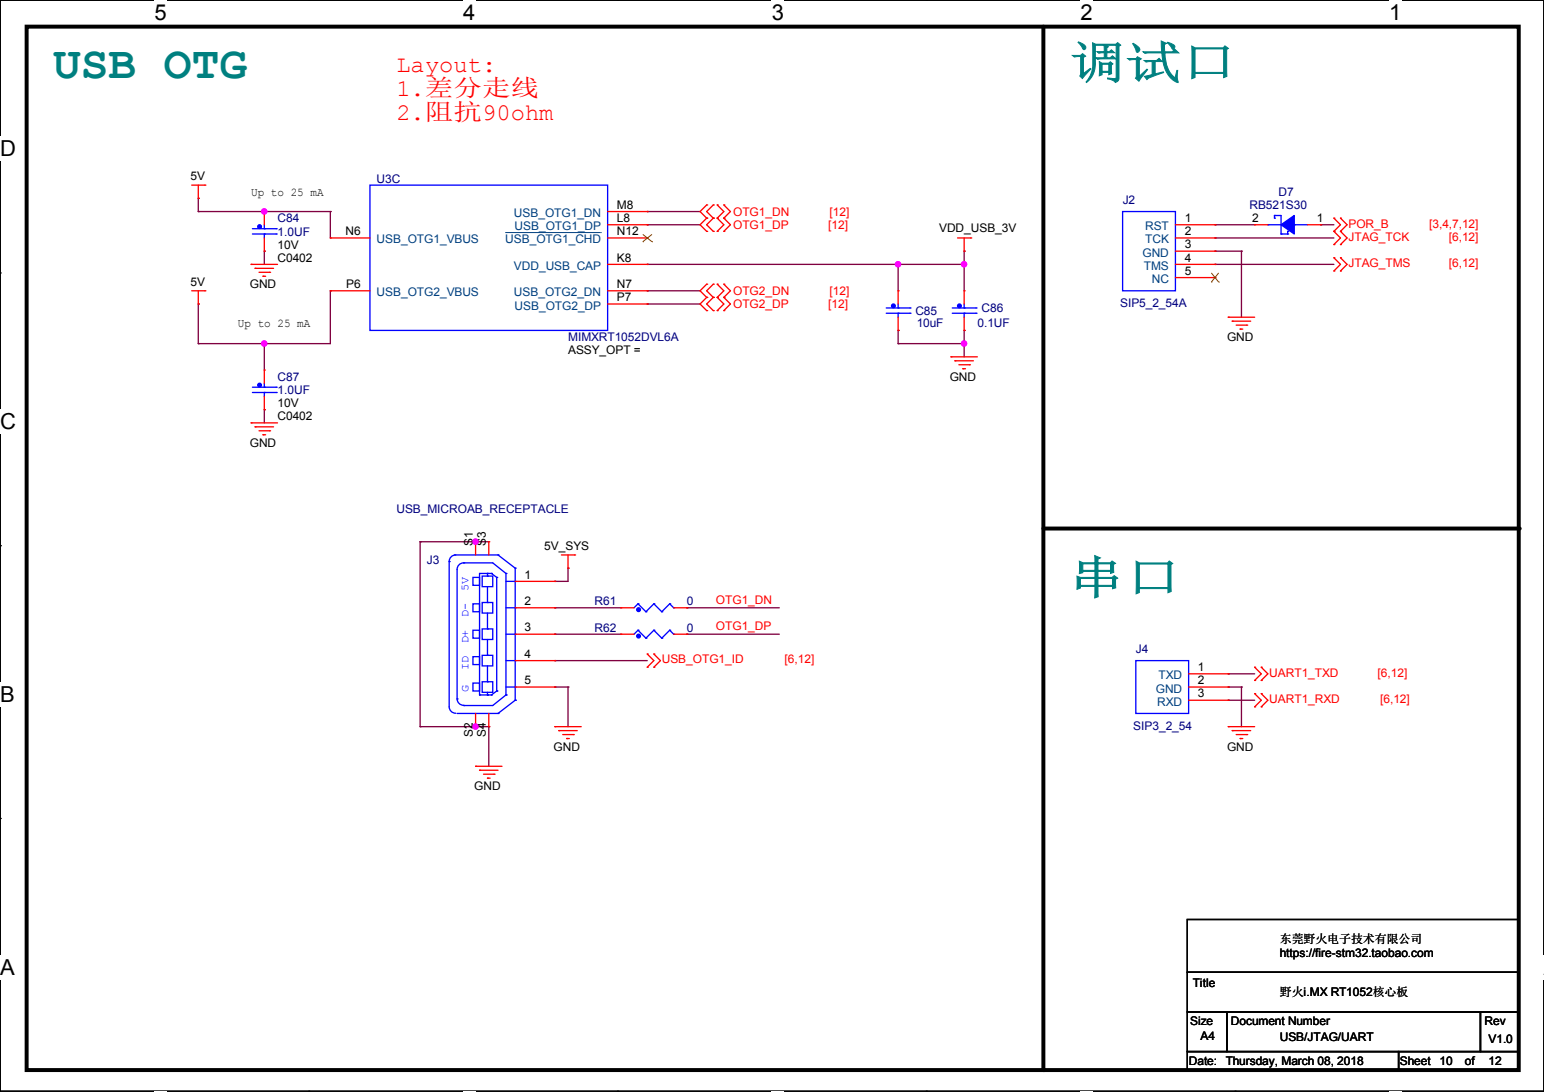
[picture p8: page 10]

东莞野火电子技术有限公司
https://fire-stm32.taobao.com

D

# Layout:

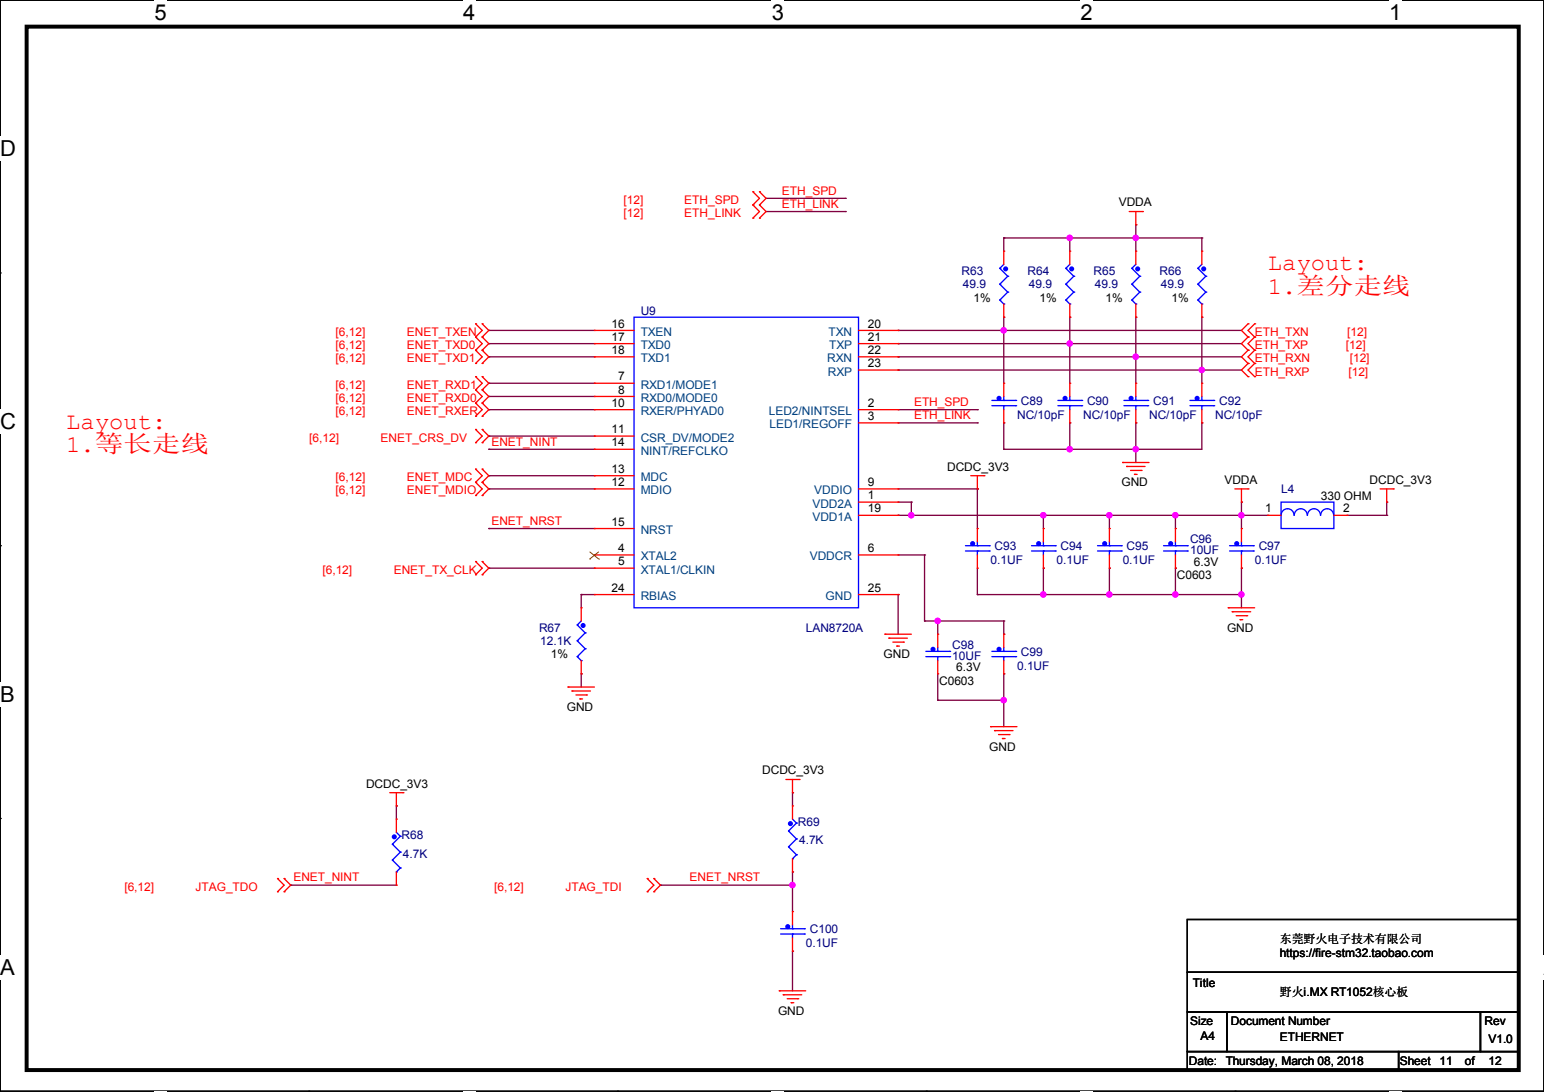
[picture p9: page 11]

东莞野火电子技术有限公司
https://fire-stm32.taobao.com

D

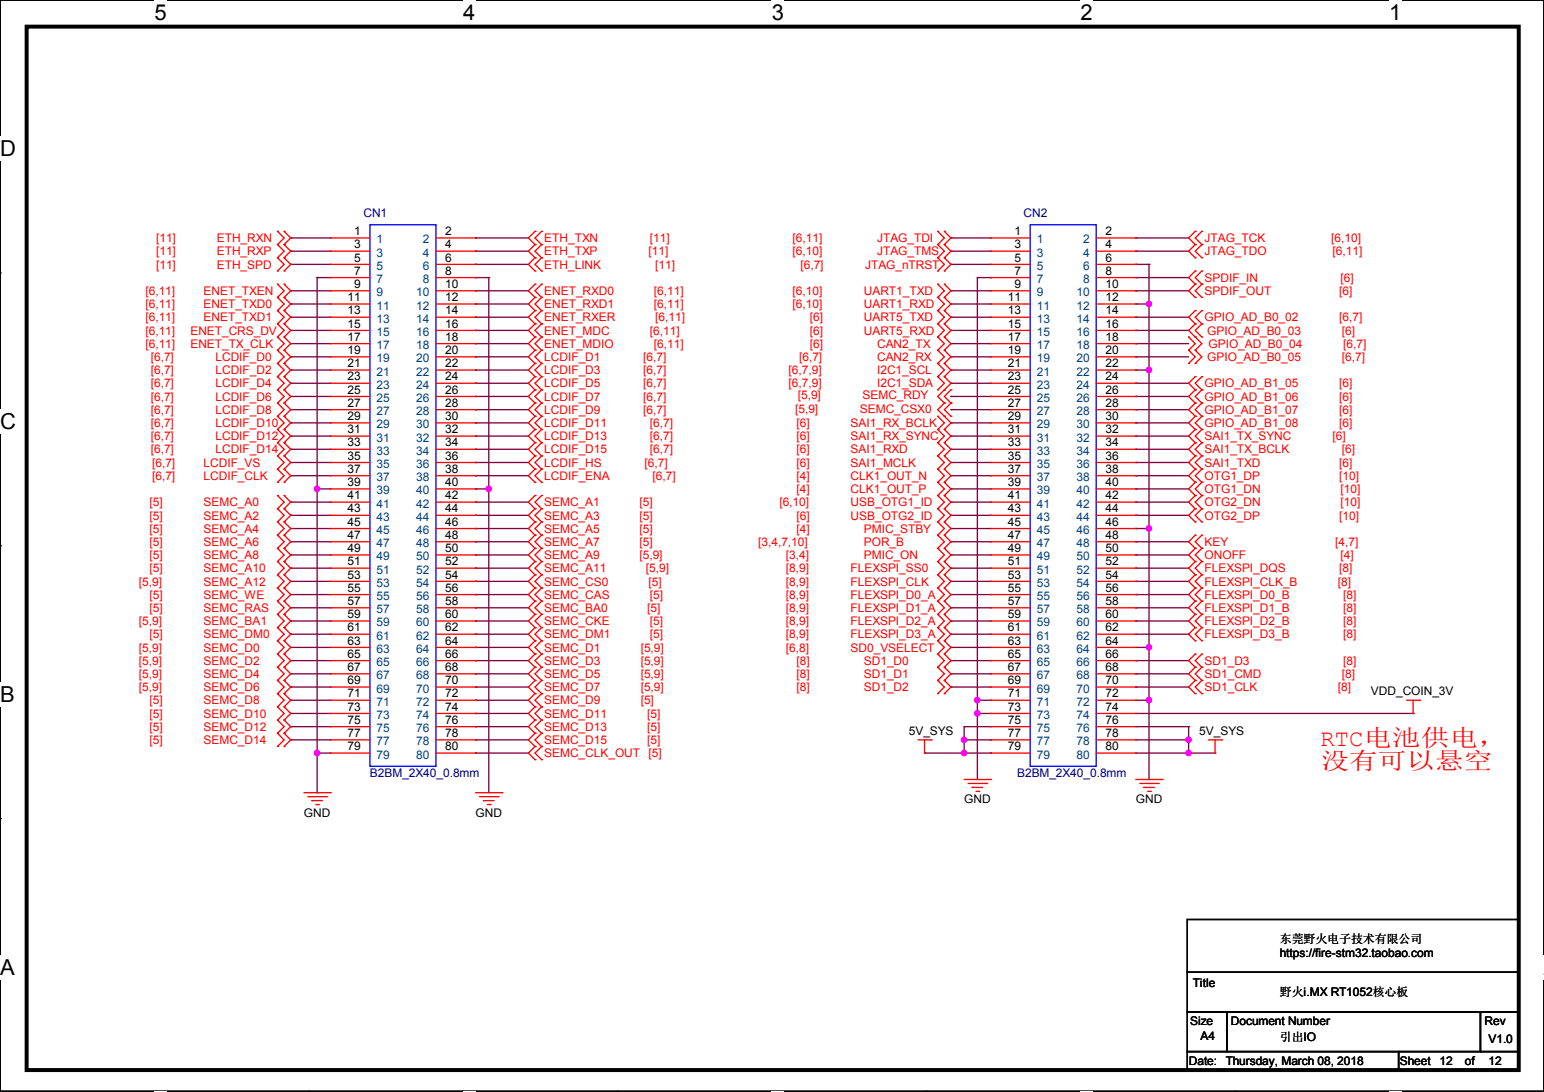
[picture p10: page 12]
RTC电池供电， 没有可以悬空; 5V_SYS; GND; VDD_COIN_3V; SEMC_BA1; SEMC_D1; SEMC_DM1; SEMC_CLK_OUT [5]; SEMC_CAS; SEMC_RAS; SEMC_BA0; SEMC_CKE; [5] SEMC_DM0; SEMC_D0; SEMC_D2; SEMC_D3; SEMC_D5; SEMC_D7; SEMC_D9; SEMC_D11; SEMC_D13; SEMC_D4; SEMC_D6; [5] SEMC_D8 [5] SEMC_D10 [5] SEMC_D12; SEMC_D14; SEMC_D15; [5] SEMC_A0 [5] SEMC_A2 [5] SEMC_A4 [5] SEMC_A6 [5] SEMC_A8 [5] SEMC_A10; SEMC_A12; [5] SEMC_WE; SEMC_A1; SEMC_A3; SEMC_A5; SEMC_A9; SEMC_A11; SEMC_A7; SEMC_CS0; [11] ETH_RXN [11] ETH_RXP [11] ETH_SPD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

东莞野火电子技术有限公司
https://fire-stm32.taobao.com

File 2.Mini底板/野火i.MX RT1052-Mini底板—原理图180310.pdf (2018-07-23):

Size A4 | Document Number 目录 | Rev V1.0
Date: Sunday, December 17, 2017 | Sheet of

https://fire-stm32.taobao.com

东莞野火电子技术有限公司

野火i.MX RT1052底板

Title

目录

Page 1 | 目录
Page 2 | 历史版本
Page 3 | 电源/USB转串口
Page 4 | 板对板连接器
Page 5 | 引出IO/启动设置
Page 6 | 以太网/摄像头
Page 7 | SD/USB

# 野火i.MX RT1052底板

https://fire-stm32.taobao.com

东莞野火电子技术有限公司

历史版本
V1.0

Title

# 历史版本

版本号 | 日期 | 作者 | 描述
V1.0 | 2017-12-12 | cancore | 初始版本

# 电源开关 LDO 3.3V

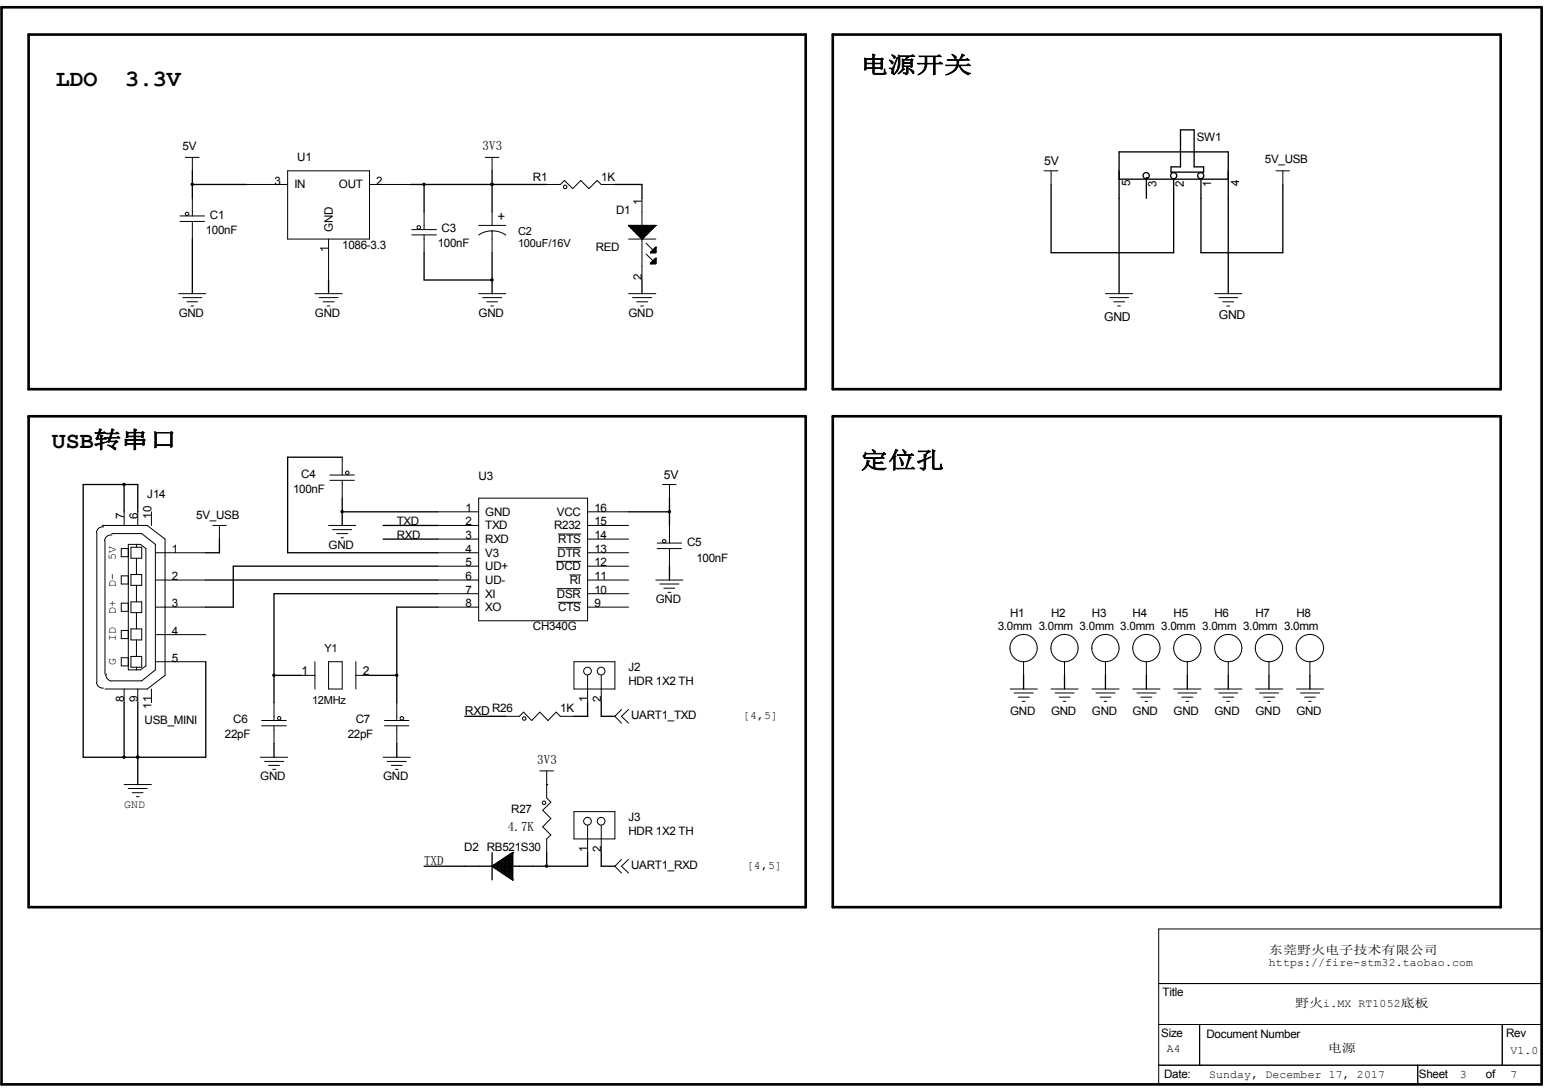
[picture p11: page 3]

东莞野火电子技术有限公司
https://fire-stm32.taobao.com

# 连接器

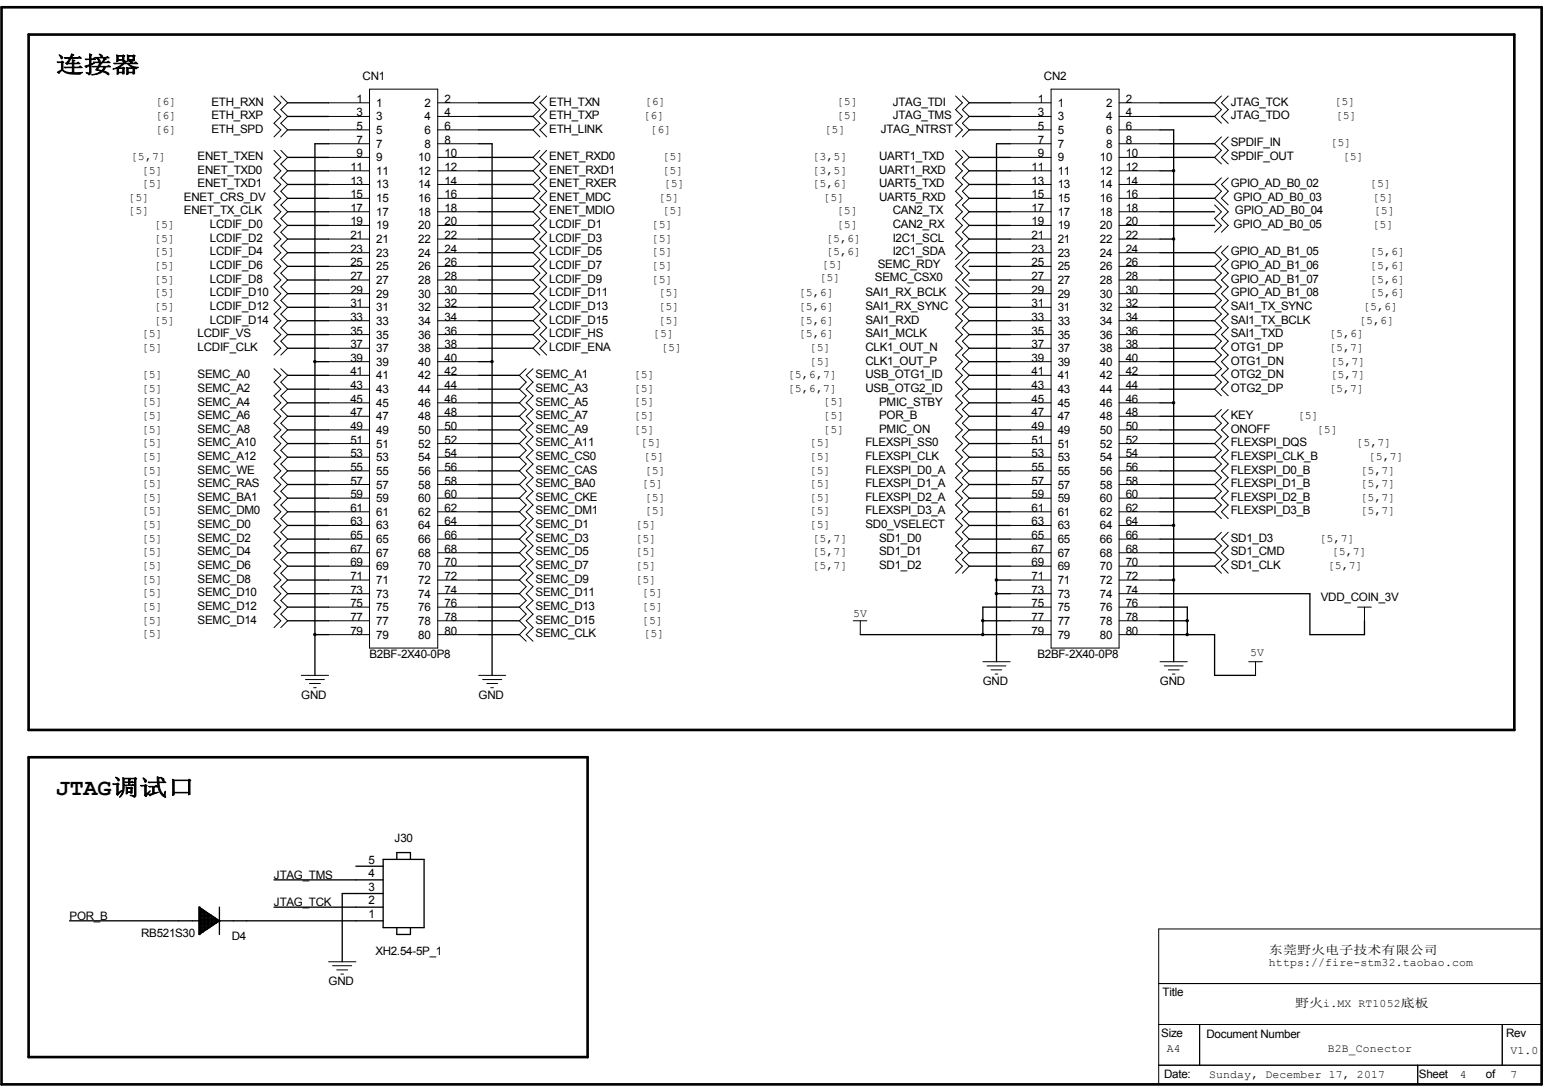
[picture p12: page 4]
B2B_Conector; Title; JTAG调试口; VDD_COIN_3V; GND; CLK1_OUT_N; SAI1_RX_BCLK SAI1_RX_SYNC SAI1_RXD SAI1_MCLK; SAI1_TX_SYNC SAI1_TX_BCLK; GPIO_AD_B1_08; SAI1_TXD; I2C1_SCL I2C1_SDA; SEMC_BA1; SEMC_D1; SEMC_DM1; SEMC_CLK; SD0_VSELECT; SEMC_RDY SEMC_CSX0; JTAG_NTRST; FLEXSPI_SS0 FLEXSPI_CLK FLEXSPI_D0_A FLEXSPI_D1_A FLEXSPI_D2_A FLEXSPI_D3_A; PMIC_STBY POR_B PMIC_ON; FLEXSPI_DQS FLEXSPI_CLK_B FLEXSPI_D0_B FLEXSPI_D1_B FLEXSPI_D2_B FLEXSPI_D3_B; KEY ONOFF; SEMC_CAS; SEMC_RAS; SEMC_BA0; SEMC_CKE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

东莞野火电子技术有限公司
https://fire-stm32.taobao.com

# 引出IO口


东莞野火电子技术有限公司
https://fire-stm32.taobao.com

引出IO/BOOT | V1.0

Date: | Sheet 5 of 7

# 摄像头接口 以太网接口


东莞野火电子技术有限公司
https://fire-stm32.taobao.com

TF卡 | USB


东莞野火电子技术有限公司
https://fire-stm32.taobao.com

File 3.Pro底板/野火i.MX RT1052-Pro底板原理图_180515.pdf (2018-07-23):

D

C

B

A | A

目录

# Page 1 目录

# 野火i.MX RT1052 Pro底板

# Page 2

# Page 3

# Page 4

# Page 5

# Page 6

# Page 8

# Page 7

# 历史版本

# 主电源

## B2B_Conector

## SENSOR/KEY/LED

## 引出IO/BOOT

## UART/CAN/RS232/RS485

## LCD/CSI

Page 9 | AUDIO
Page 10 Page 11 | WIFI/SD USB HUB/OTG
Page 12 Page 13 | LVDS ETHERNET/SPDIF

Title

Size | Document Number | Rev
Date: | Sheet | of
目录 | V1.0

野火i.MX RT1052 Pro底板

东莞野火电子技术有限公司
https://fire-stm32.taobao.com

A4

Tuesday, May 15, 2018 | 1 | 12

Title

目录 | V1.0

野火i.MX RT1052 Pro底板

东莞野火电子技术有限公司
https://fire-stm32.taobao.com
Tuesday, May 15, 2018 | 1 | 12

Title

目录 | V1.0

野火i.MX RT1052 Pro底板

东莞野火电子技术有限公司
https://fire-stm32.taobao.com
Tuesday, May 15, 2018 | 1 | 12

D

C

B

A | A

# 历史版本

# 版本号

V0.1 | 2018-03-13
| 日期 | 设计 | 描述
| | cancore | 初始版本
V0.2 | 2018-04-19 | cancore | 同轴与串口之间增加跳帽，修改部分封装及结构
V1.0 | 2018-05-02 | cancore | 更换sensor,增加SD卡供电控制电路

Title

历史版本 | V1.0

野火i.MX RT1052 Pro底板

东莞野火电子技术有限公司
https://fire-stm32.taobao.com
Tuesday, May 15, 2018 | 2 | 12

Title

历史版本 | V1.0

野火i.MX RT1052 Pro底板

东莞野火电子技术有限公司
https://fire-stm32.taobao.com
Tuesday, May 15, 2018 | 2 | 12

Title

历史版本 | V1.0

野火i.MX RT1052 Pro底板

东莞野火电子技术有限公司
https://fire-stm32.taobao.com
Tuesday, May 15, 2018 | 2 | 12

D

12V/3A


GND GND GND GND

GND GND

东莞野火电子技术有限公司
https://fire-stm32.taobao.com

D

# 连接器

JTAG调试口; RTC电池; VDD_COIN_3V; GND; [5] CLK1_OUT_N; SAI1_RX_BCLK; SAI1_RX_SYNC; SAI1_RXD; SAI1_MCLK; SAI1_TX_SYNC; SAI1_TX_BCLK; GPIO_AD_B1_08; SAI1_TXD; I2C1_SCL; I2C1_SDA; [5] SEMC_BA1; SEMC_D1; SEMC_DM1; SEMC_CLK; [5] SD0_VSELECT; [5] SEMC_RDY [5] SEMC_CSX0; JTAG_nTRST; [5] FLEXSPI_SS0 [5] FLEXSPI_CLK [5] FLEXSPI_D0_A [5] FLEXSPI_D1_A [5] FLEXSPI_D2_A [5] FLEXSPI_D3_A; [5] PMIC_STBY; POR_B; PMIC_ON; FLEXSPI_DQS; FLEXSPI_CLK_B; FLEXSPI_D0_B; FLEXSPI_D1_B; FLEXSPI_D2_B; FLEXSPI_D3_B; KEY; ONOFF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

东莞野火电子技术有限公司
https://fire-stm32.taobao.com

野火i.MX RT1052 Pro底板

D

引出IO口 | A | B


东莞野火电子技术有限公司
https://fire-stm32.taobao.com

D

# 六轴传感器


ALS+PS+IRLED（三合一）

东莞野火电子技术有限公司
https://fire-stm32.taobao.com

D

USB转串口 | 串口RS232


东莞野火电子技术有限公司
https://fire-stm32.taobao.com

D

# 液晶接口


东莞野火电子技术有限公司
https://fire-stm32.taobao.com

D

# MIC插头


C107 | 1uF | LINPUT2 3

东莞野火电子技术有限公司
https://fire-stm32.taobao.com

D

# WIFI


东莞野火电子技术有限公司
https://fire-stm32.taobao.com

D

# USB HUB


东莞野火电子技术有限公司
https://fire-stm32.taobao.com

D

RGB565转LVDS | 驱屏接口


东莞野火电子技术有限公司
https://fire-stm32.taobao.com

D

以太网接口 | 光纤接口


东莞野火电子技术有限公司
https://fire-stm32.taobao.com
